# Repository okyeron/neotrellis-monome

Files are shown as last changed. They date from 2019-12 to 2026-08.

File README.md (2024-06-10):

# neotrellis monome compatible grid

## What is it?

Code to use a set of [Adafruit NeoTrellis boards](https://www.adafruit.com/product/3954) as a monome grid clone using an off-the-shelf microcontroller.

Tested mostly using a Teensy 3.2 microcontroller. Teensy 4 should work the same, but it does not have USB pads broken out to use a USB breakout board. 

[There is code](neotrellis_monome_m0) for using an Adafruit SAMD21/51 M0/M4 boards like the Feather and ItsyBitsy, but this will probably require compiling the firmware for your specific board. Compiled firmwares for Feather M4 are in the repo.

Code for [RP2040](neotrellis_monome_rp2040) is also available, but this will probably require compiling the firmware for your specific board.

## compatibility

### Max or other computer-based applications

At the time of writing, this code works as expected with the neotrellis-grid connected to a computer with Max running monome patches.

Some people have reported issues with the neotrellis-grid getting recognized by Windows 10. Windows users are advised to install serialosc 1.4.3 and bonjour print services (v2.0.2?).

### ansible / teletype / trilogy modules

2021 updates to ansible / teletype / trilogy modules now support the neotrellis-grid. It should work without modifications.

### norns /norns shield

As of update version 210607 (June 2021) it should be plug and play. Previous versions are unsupported.

###  Fates

For Fates devices this should be functional by default on the most recent firmwares.

# Build

## BOM:  

8 [Adafruit NeoTrellis driver boards](https://www.adafruit.com/product/3954) [alt [Mouser](https://www.mouser.com/ProductDetail/485-3954) | [Digikey](https://www.digikey.com/products/en?keywords=1528-2712-ND) ]    

8 [Button keypads](http://www.adafruit.com/product/1611) [alt [Mouser](https://www.mouser.com/ProductDetail/485-1611) | [Digikey](https://www.digikey.com/products/en?keywords=1528-1559-ND) ]    

1 [Adafruit micro B USB Breakout](http://www.adafruit.com/product/1833) [alt [Mouser](https://www.mouser.com/ProductDetail/485-1833) | [Digikey](https://www.digikey.com/products/en?keywords=1528-1383-ND) ]    

1 [Teensy 3.2](https://www.pjrc.com/store/teensy32.html) [alt [Adafruit](https://www.adafruit.com/product/2756) ]  

### optional

1 [Adafruit STEMMA/JST-PH 4-pin cable](https://www.adafruit.com/product/3568) - for testing inndividual neotrellis boards before assembly. Cut the cable in half and wire to the appropriate pins on a Teensy or other microcontroller (VIN, GND, SCL, SDA). See the neotrellis boards themselves for the pin-out.

Standard pin headers - 10 1x5 pin headers can be used for joining the neotrellis boards together. [See video](https://www.youtube.com/watch?v=petILmGcNwQ)

Flexible PCB Carrier (Flexi PCB) for mounting the teensy to the neotrellis boards. [Teensy version for sale here](https://www.denki-oto.com/store/p45/Flexible_PCB_Carrier_for_Neotrellis_Grid.html#/)  or [Pico version here](https://www.denki-oto.com/store/p107/Flexible_PCB_Carrier_for_Neotrellis_Grid_and_Pi_Pico.html#/)

Q: Do I need the Flexible PCB Carrier if I have the dink-ii board?
A: No. The dink-ii board replaces the Flexi-PCB.

## before building

* Test each neotrellis board individually using the Adafruit examples in the `File>Examples>Adafruit seesaw Library>Neotrellis` menu. The Basic sketch is good for testing individual boards. The `multitrellis>basic` sketch is good once you have all the boards connected and addresses assigned.

## neotrellis building

* Review the [Adafruit tutorial on the neotrellis](https://learn.adafruit.com/adafruit-neotrellis/arduino-code) boards. 

* [see this video](https://www.youtube.com/watch?v=petILmGcNwQ) for an example of how to join the boards together

## neotrellis address assignment

* [see this graphic](neotrellis_addresses.jpg) for a default layout of addresses and jumper positions for 8 neotrellis boards.

* new default address order in the code for 16x8 layout (__NOTE__ the address are in reverse order in the code - as compared to the graphic above):  
```
  { Adafruit_NeoTrellis(0x32), Adafruit_NeoTrellis(0x30), Adafruit_NeoTrellis(0x2F), Adafruit_NeoTrellis(0x2E)}, // top row
  { Adafruit_NeoTrellis(0x33), Adafruit_NeoTrellis(0x31), Adafruit_NeoTrellis(0x3E), Adafruit_NeoTrellis(0x36) } // bottom row
```

* see this [neotrellis i2c address chart](NeoTrellis_Addresses.txt) if you want to define your own addresses

* Don't worry about the INT pin - it's not used in the grid software.

## firmware flashing - Teensy

### Load pre-compiled firmware w/ TyUploader

Get the firmware "hex" file from directory in this repo (download the entire repo ZIP file - not just individual files).

Get TyTools [from GitHub here](https://github.com/Koromix/tytools/releases). More info here (https://koromix.dev/tytools).

Install TyUploader and open it. Be sure your neotrellis-grid is plugged in. The grid/Teensy should show up in the TyUploader application... or select Teensy or Teensyduino from the pull down menu if needed.

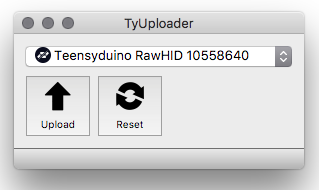
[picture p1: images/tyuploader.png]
tyupdater


Click the Upload button and select the firmware hex file you want to upload. This should upload the firmware and the neotrellis-grid should reboot. That's it.

### If you want to copile the firmware yourself to make changes, etc...

In Arduino/Teensyduino - be sure you have the settings in  `Tools -> USB Type` set to `Serial`

Not critical, but set `Tools -> CPU Speed` to `120 MHz (overclock)`

For reference: [here's a forum post on how to flash Teensy firmware](https://llllllll.co/t/how-to-flash-the-firmware-on-a-teensy-micro-controller/20317)

## other microcontrollers  

See the repo directories for using the Adafruit Neotrellis M4 device (8x4 grid) or SAMD M0/M4 devices (like Adafruit's Feather/ItsyBitsy/QtPy/etc). Precompiled UF2 firmwares are available in those directories for some configurations.

## troubleshooting / testing 

* Triple check your address jumpers - [see this graphic](neotrellis_addresses.jpg) for a default layout of addresses and jumper positions for 8 neotrellis boards.

* Be sure you have the Adafruit Seesaw libraries installed and are up to date (via the Arduino/Teensyduino Library Manager)

* Use the [multitrellis_test](multitrellis_test/multitrellis_test.ino) sketch to test fully assembled grid before flashing neotrellis_monome_teensy.

* Be aware - the multitrellis array will fail to initialize if the addresses are wrong, or the wrong number of boards are attached. If you get no LEDs are just some LEDs - then your addresses are likely the problem.

* There are Teensy specific `i2c_t3` example sketches which can be used to double check your i2c addresses. See `File>Examples>i2c_t3>basic_scanner` in Arduino/Teensyduino for more.

## build help / support / troubleshooting

[see this thread](https://llllllll.co/t/diy-monome-compatible-grid-w-adafruit-neotrellis/28106?u=okyeron) on the lines forum for assistance.

## alternate firmware for color palettes 

https://github.com/oldmanfury/neotrellis-grid-paletted

## testing with serialosc on MacOS

If you already have serialosc installed/running, you may need to unload serialosc to get arduino to properly flash the teensy, then load serialosc to get Max to recognize the grid.  

`launchctl unload /Library/LaunchAgents/org.monome.serialosc.plist`  
`launchctl load /Library/LaunchAgents/org.monome.serialosc.plist`  

Max apps for testing:  
[Monome Home](https://github.com/monome-community/monome-home)  
[test-grid](https://github.com/monome/serialosc.maxpat)  

# Case / Enclosure

[Work in progress](<enclosure/README.md>)

# references

### mext / monome serial protocol

The mext protocol is used for serial communication - same as what is used in most recent monome devices.

### serialosc / libmonome

`serialosc` is required for serial communication with MacOS/Windows computers and OSC devices. Linux may use `serialosc` or `libmonome` depending on the application. `libmonome` is basically driver code which also facillitates monome serial communication.

You can get both `serialosc` and `libmonome` code from [monome github page](https://github.com/monome), and building them is well documented on official linux docs (they work for macOS as well), read part *2 Preparing your system: serialosc* (ignoring the `sudo apt-get` - I was missing `liblo`, but it's available on homebrew): [monome.org/docs/linux/](https://monome.org/docs/linux/).

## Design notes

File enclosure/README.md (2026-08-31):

# neotrellis grid enclosure

This is one example of an enclosure for the neotrellis grid - using a Teensy 3.2 and Adafruit [USB micro breakout](https://www.adafruit.com/product/1833)

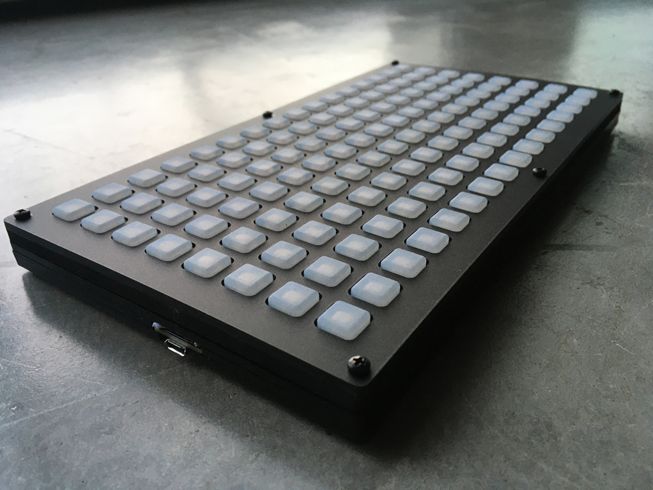
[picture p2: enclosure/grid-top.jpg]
<grid>


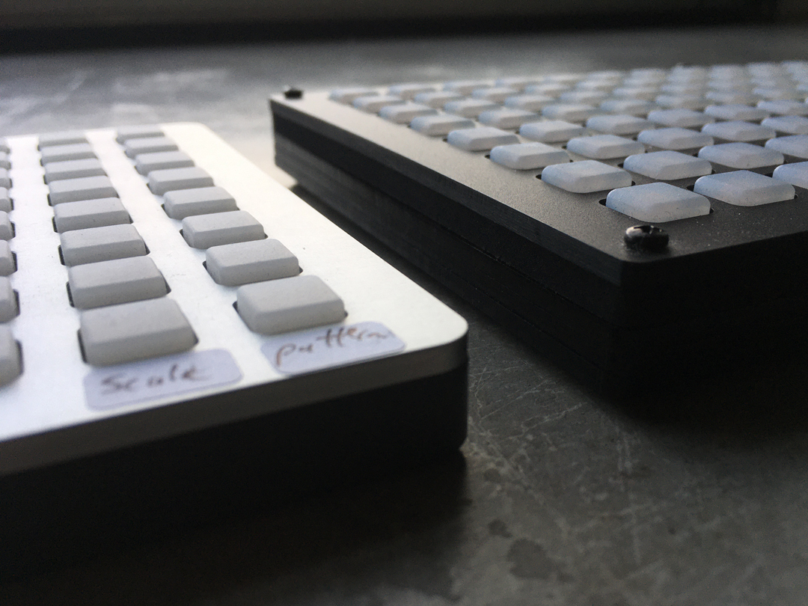
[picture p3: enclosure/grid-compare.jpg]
<grid compare with monome grid>


It's a "stack" of laser cut 3mm acrylic and one layer of 5mm EVA foam. I'm using six 2.5M 11mm standoffs and 2.5M screws to attach everything.  

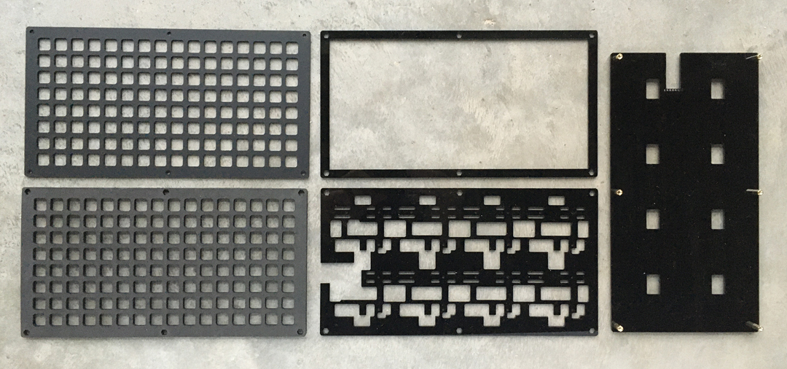
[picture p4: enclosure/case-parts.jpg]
<stack parts>


(this photo is a slightly older layout)

## USB micro breakout

The USB micro breakout is used to breakout 5v power/data from the Teensy and workaround a current limiter on the Teensy 3.2's usb port. This also to provide a cheap and easily replaceable part if the jack gets damaged (Teensy's are a huge pain if the USB jack breaks off).

NOTE - The usb breakout setup here will not work with the Teensy 4. But it appears the Teensy 4 does not have the current limiting issue. However, using a T4 would require a slightly different case design/layout.

# Pins / Soldering / Assembly

## Old way - Free-wiring
Pins used on the Teensy are VIN (5v from USB), GND, D+, D- (SMD pads on the underside), and then SCL (pin 19), SDA (pin 18).  

Put a piece of electrical/kapton tape over the back of the teensy to avoid potential shorts when you stack it up (its a bit of a tight squeeze).  

Just in case - also put a piece of electrical/kapton tape on the neotrellis board under where the teensy sits.  

Putting the Teensy in the case, you want to be sure it's as flat as possible (see pix).

Kinda ugly example of the teensy and usb breakout wiring for this case layout: 

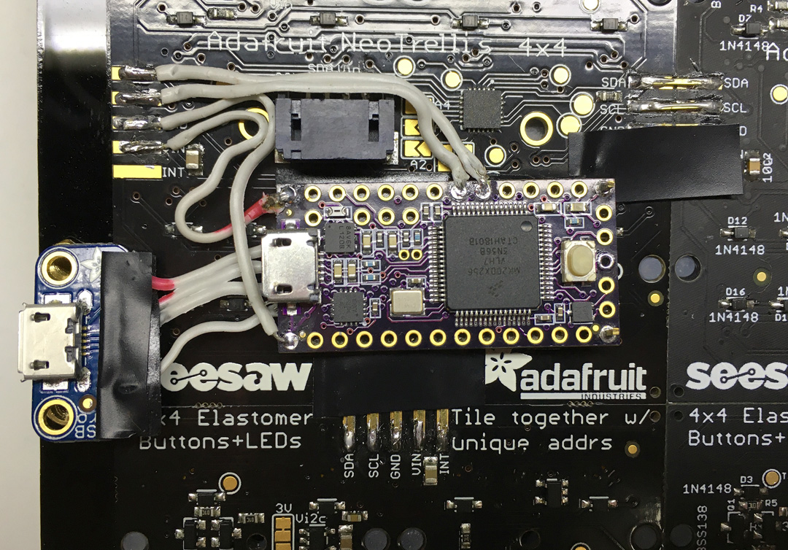
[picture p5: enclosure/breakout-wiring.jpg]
<teensy with usb breakout>


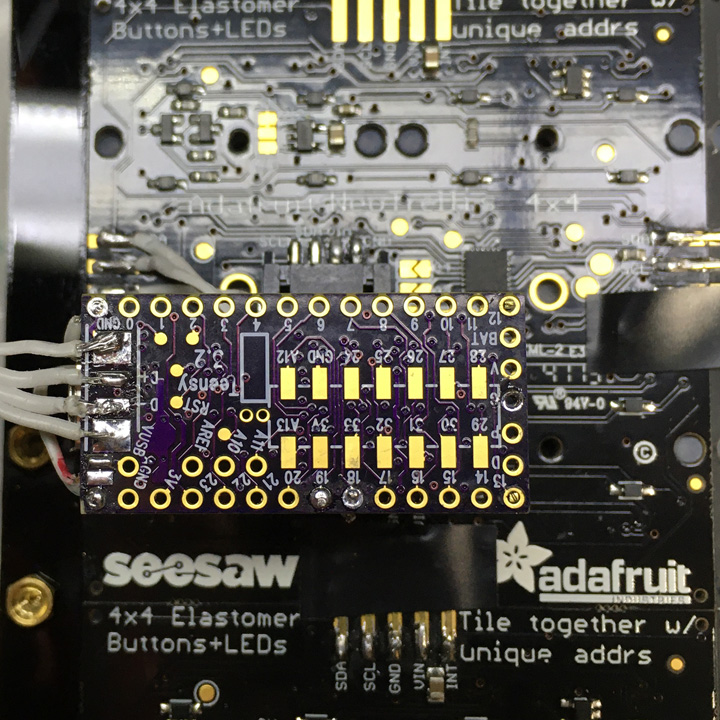
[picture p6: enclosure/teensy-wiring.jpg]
<teensy with usb breakout>


## New way - flexible pcb carrier

As a replacement for the slightly janky free-wiring, I designed a flexible PCB carrier for the Teensy and the USB breakout.

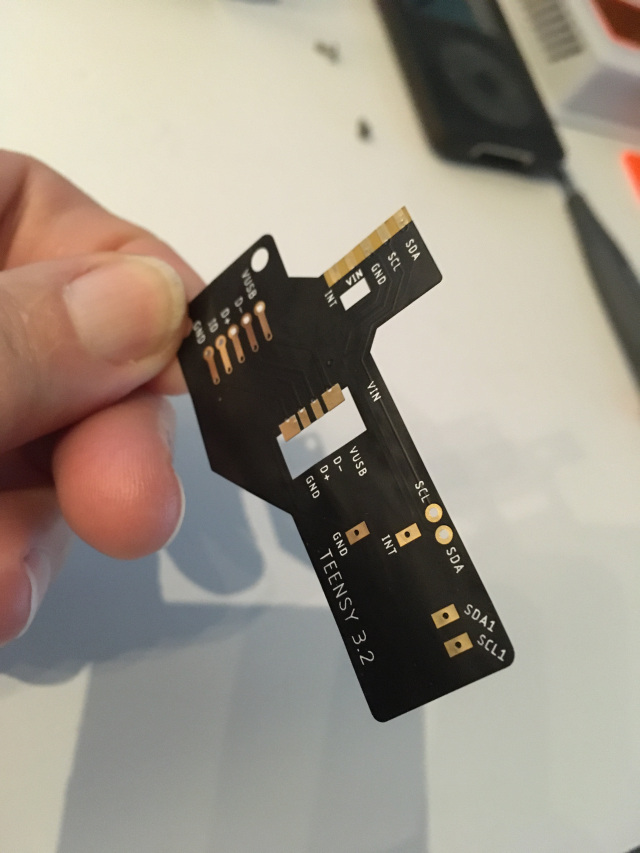
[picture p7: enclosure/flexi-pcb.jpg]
<flexi-pcb>


Unfortunately the flexi-pcb is no longer available.  

## Newest way - use a purpose built controller  

The flex-pcb idea was deprecated as I made the [dink-ii controller](https://denki-oto.com/products/dink-ii-i2c-microcontroller) board which is plug-n-play (no soldering) and less expensive than a combination of other microcontroller + flex-pcb.

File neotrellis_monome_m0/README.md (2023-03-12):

# neotrellis monome compatible grid

Neotrellis Grid Code for Adafruit M0 and M4 controllers.

This code should work with any of the various Adafruit SAMD21/51 M0/M4 controllers such as Feather, ItsyBitsy, etc. 

__NOTE__ - You will need to recompile the code for the specific board you are using. Compiled firmwares such as `neotrellis_m4_8x8_featherM4.UF2` will ONLY work on that specific board type. 

Step 1: Be sure update to the most recent TinyUSB library version. If you're using Arduino, it's best to use Manage Libraries in Arduino to install/update TinyUSB.

Step 2: Be sure you check the board addresses for your build and adjust the code as needed if you do something different than the default described here.

## Adafruit Feather M4 Kit
[Adafruit 8x8 NeoTrellis Feather M4 Kit Pack](https://www.adafruit.com/product/1929)

If you have this (or have built an 8x8 grid with Feather M4) you can use the enclosed compiled firmware [neotrellis_m4_8x8_featherM4.UF2](neotrellis_m4_8x8_featherM4.UF2) assuming your setup uses the following addresses 
```
{ Adafruit_NeoTrellis(0x2E), Adafruit_NeoTrellis(0x30) },
{ Adafruit_NeoTrellis(0x32), Adafruit_NeoTrellis(0x36) }

```

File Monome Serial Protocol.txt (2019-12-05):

## serial protocol

//// input (to serialosc/device)

// sys

/sys/prefix
/sys/port
/sys/host

pattern:	/sys/query
desc:		request device information
serial:		[0x00]

pattern:	/sys/id
desc:		request device ID string
serial:		[0x01]

pattern:	/sys/size
desc:		request grid size
serial:		[0x05]

// led-grid

pattern:	/prefix/led/set x y s
desc:		set led state
args:		x = x value (0-255)
			y = y value (0-255)
			s = on/off (0-1)
serial:		if s = 0, [0x10, x, y]
			if s = 1, [0x11, x, y]

pattern:	/prefix/led/all s
desc:		set all leds
args:		s = on/off (0-1)
serial:		if s = 0, [0x12]
			if s = 1, [0x13]

pattern:	/prefix/led/map x y d[8]
desc:		set 8x8 block of leds, with offset
args:		x = x offset, will be floored to multiple of 8 by firmware
			y = y offset, will be floored to multiple of 8 by firmware
			d[8] = bitwise display data
serial:		[0x14, x, y, d[8]]

pattern:	/prefix/led/row x y d
desc:		set 8x1 block of leds, with offset
args:		x = x offset, will be floored to multiple of 8 by firmware
			y = y offset
			d = bitwise display data
serial:		[0x15, x, y, d]
note:		d can be an array. for each additional element, another serial packet is sent, with x offset incremented by 8.

pattern:	/prefix/led/col x y d
desc:		set 1x8 block of leds, with offset
args:		x = x offset
			y = y offset, will be floored to multiple of 8 by firmware
			d = bitwise display data
serial:		[0x16 x, y, d]
note:		d can be an array. for each additional element, another serial packet is sent, with y offset incremented by 8.

pattern:	/prefix/led/intensity i
desc:		set intensity for entire grid
args:		i = intensity (0-15)
serial:		[0x17, i]

pattern:	/prefix/led/level/set x y i
desc:		set led intensity
args:		x = x value (0-255)
			y = y value (0-255)
			i = intensity (0-255)
serial:		[0x18, x, y, i]

pattern:	/prefix/led/level/all s
desc:		set all leds to level
args:		i = intensity (0-255)
serial:		[0x19, i]

pattern:	/prefix/led/level/map x y d[64]
desc:		set 8x8 block of leds levels, with offset
args:		x = x offset, will be floored to multiple of 8 by firmware
			y = y offset, will be floored to multiple of 8 by firmware
			d[64] = intensities
serial:		[0x1A, x, y, d[64]]

pattern:	/prefix/led/level/row x y d[8]
desc:		set 8x1 block of led levels, with offset
args:		x = x offset, will be floored to multiple of 8 by firmware
			y = y offset
			d[8] = intensities
serial:		[0x1B, x, y, d[8]]
note:		if d[8] has more than 8 elements (multiple of 8) send multiple serial packets with proper offset

pattern:	/prefix/led/level/col x y d[8]
desc:		set 1x8 block of led levels, with offset
args:		x = x offset
			y = y offset, will be floored to multiple of 8 by firmware
			d = bitwise display data
serial:		[0x1C x, y, d[8]]
note:		if d[8] has more than 8 elements (multiple of 8) send multiple serial packets with proper offset

// led-ring

pattern:	/prefix/ring/set n x a
desc:		set led x of ring n to value a
args:		n = ring number
			x = led number
			a = value (0-15)
serial:		[0x90, n, x, a]

pattern:	/prefix/ring/all n a
desc:		set all leds of ring n to a
args:		n = ring number
			a = value
serial:		[0x91, n, a]

pattern:	/prefix/ring/map n d[32]
desc:		set leds of ring n to array d
args:		n = ring number
			d[32] = 64 states, 4 bit values, in 32 consecutive bytes
			d[0] (0:3) value 0
			d[0] (4:7) value 1
			d[1] (0:3) value 2
			....
			d[31] (0:3) value 62
			d[31] (4:7) value 63
serial:		[0x92, n d[32]]

pattern:	/prefix/ring/range n x1 x2 a
desc:		set leds inclusive from x1 and x2 of ring n to a
args:		n = ring number
			x1 = starting position
			x2 = ending position
			a = value
serial:		[0x93, n, x1, x2, a]
note:		set range x1-x2 (inclusive) to a. wrapping supported, ie. set range 60,4 would set values 60,61,62,63,0,1,2,3,4. always positive direction sweep. ie. 4,10 = 4,5,6,7,8,9,10 whereas 10,4 = 10,11,12,13...63,0,1,2,3,4

//// output (from serialosc/device)

// sys

pattern:	/sys/query s n
desc:		device information
serial:		[0x00, s, n]
args:		s = subsection, enumerated as strings [null, "led-grid", "key-grid", "digital-out", "digital-in", "encoder", "analog-in", "analog-out", "tilt", "led-ring"]
			n = number

pattern:	/sys/id s[64]
desc:		device ID string
serial:		[0x01, s[64]]
args:		s = id string, 64 chars

pattern:	/sys/size x y
desc:		grid size
serial:		[0x05, x, y]
args:		x = x size
			y = y size

// key

pattern:	/prefix/key x y s
desc:		key state change
serial:		if s = 0 [0x00, x, y] key up
			if s = 1 [0x01, x, y] key down
args:		x = x position
			y = y position

// encoder

pattern:	/prefix/enc/delta n d
desc:		encoder position change
serial:		[0x50, n, d]
args:		n = encoder number
			d = delta (signed char)

pattern:	/prefix/enc/key n d
desc:		encoder position change
serial:		if d = 0 [0x51 n] key up
			if d = 1 [0x52 n] key down
args:		n = encoder number

monome protocol
---------------

- extended to support variety of control, room for extensibility
- to be implemented on mk, new editions, arc, arc-variants (axis?)
- take advantage of i2c device chain system
- remove dependence on device usb serial number, replace with query system

notes
-----

new serial prefix: tty.usbserial-m0000000

mk set-number of grids, firmware versions for each size 1/2/4

should grid offsets live inside the grid subsystem?
	applies to both led-grid and key-grid.
	should each have it's own?

"all" vs "clear"

legacy bridge
	ie /press => /key
	ie /clear => /led/all 0

structure
---------

first byte of packet is identifier in the form:

[(a << 4) + b]

a = section (ie. system, key-grid, digital, encoder, led grid, tilt)
b = command (ie. query, enable, led, key, frame)

organized by section:

---------------------------------------------------------------------
0 system
---------------------------------------------------------------------

note: most of these messages are not accessible via OSC
	intended for device configuration

to device:
----------

OSC:
/sys/query
	mapped to 0x00
/sys/id
	mapped to 0x01
/sys/size
	mapped to 0x05

0x00 system / query
bytes: 1
structure: [0x00]
description: request device information
action: response, 0x00 (see below)
OSC: /sys/query

0x01 system / query ID
bytes: 1
structure: [0x01]
description: request device ID (text string, trailing space needs to be stripped)
action: response, 0x01 (see below)

0x02 system / write ID
bytes: 33
structure: [0x02, d0..31]
description: write ID (text string)
response: confirms written id, 0x01

0x03 system / request grid offsets
bytes: 1
structure: [0x03]
description: request grid offsets. device will respond for each connected grid.
action: response, 0x02

0x04 system / set grid offset
bytes: 4
structure: [0x04, n, x, y]
n = grid number
x = x offset (floored to multiple of 8 by firmware)
y = y offset (floored to multiple of 8 by firmware)
description: set grid offset to (x, y)

0x05 system / request grid size
bytes: 1
structure: [0x05]
description: request grid size. device will respond with x,y
action: response, 0x03

0x06 system / set grid size
bytes: 3
structure: [0x06, x, y]
x = x size
y = y size
description: set grid size to (x, y)

0x07 system / get ADDR (scan)
bytes: 1
structure: [0x07]
description: request list of connected components (i2c ADDRs)

0x08 system / set ADDR
bytes: 3
structure: [0x08, a, b]
a = ADDR to set
b = new ADDR value
description: set ADDR. writes internal eeprom. probably should reset afterwards?

0x0F system / query firmware version
bytes: 1
structure: [0x0F]
description: request firmware version

from device:
------------

OSC:
/sys/query
	mapped to 0x00
/sys/id
	mapped to 0x01
/sys/size
	mapped to 0x03

0x00 system / query response
bytes: 3
structure: [0x00, a, b]
a = section (grids, encs)
	1-15 (0 is system)
b = number (how many connected)
	0-255
description: response to request for component availability. multiple responses will be sent, one for each section. for example, if two grids are connected and 8 encoders, the response would be [0,1,2] [0,2,8]
OSC: /sys/query a b
	where a is a text translation, b is number available. a = [null, "led-grid", "key-grid", "digital-out", etc]

0x01 system / ID
bytes: 33
structure: [0x01, d0..31]
description: respond with ID (text string)

0x02 system / report grid offset
bytes: 4
structure: [0x02, n, x, y]
n = grid number
x = x offset
y = y offset
description: response to query, grid offset (x, y)

0x03 system / report grid size
bytes: 3
structure: [0x03, x, y]
x = x
y = y
description: response to query, grid size (x, y)

0x04 system / report ADDR
bytes: 3
structure: [0x0F, a, b]
a = ADDR
description: found device at ADDR, type b

0x0F system / report firmware version
bytes: 9
structure: [0x0F, v[8]]
v = version, 8 character string
description: firmware version

---------------------------------------------------------------------
1 led-grid
---------------------------------------------------------------------

to device:
----------

OSC:
/led/set x y [0/1]
	mapped to 0x10 and 0x11
/led/all [0/1]
	mapped to 0x12 and 0x13
/led/map x y d[8]
	mapped to 0x14
/led/row x y d
	mapped to 0x15
/led/col x y d
	mapped to 0x16
/led/intensity x
	mapped to 0x17

0x10 led-grid / led off
bytes: 3
structure: [0x10, x, y]
description: turn off led at (x,y)

0x11 led-grid / led on
bytes: 3
structure: [0x11, x, y]
description: turn on led at (x,y)

0x12 led-grid / all off
bytes: 1
structure: [0x12]
description: all leds off

0x13 led-grid / all on
bytes: 1
structure: [0x13]
description: all leds on

0x14 led-grid / map (frame)
bytes: 11
structure: [0x14, x, y, d0..7]
x = x offset (floored to multiple of 8 by firmware)
y = y offset (floored to multiple of 8 by firmware)
d = led states, 8x8 block (64 bits, 8 bytes)
	sequential bytes represent rows (series of x values)
description: write 8x8 block of led data

0x15 led-grid / row
bytes: 4
structure: [0x15, x, y, d]
x = x offset (floored to multiple of 8 by firmware)
y = y value
d = led states, 8 bits
	bitwise
description: write row of 8 bits at y, offset by x

0x16 led-grid / col
bytes: 4
structure: [0x15, x, y, d]
x = x value
y = y offset (floored to multiple of 8 by firmware)
d = led states, 8 bits
	bitwise
description: write row of 8 bits at x, offset by y

0x17 led-grid / intensity
bytes: 2
structure: [0x18, a]
a = intensity
	0-255 (scaled inside firmware)
description: change overall led intensity

0x18 led-grid / set led intensity
bytes: 4
structure: [0x18, x, y, i]
i = intensity
	0-255 (scaled inside firmware)
description: set led (x,y) to intensity i

0x19 led-grid / set all leds to specified intensity
bytes: 2
structure: [0x19, i]
i = intensity
	0-255 (scaled inside firmware)
description: set all leds to intensity i

0x1A led-grid / map intensity
bytes: 67
structure: [0x14, x, y, d0..63]
x = x offset (floored to multiple of 8 by firmware)
y = y offset (floored to multiple of 8 by firmware)
d = led intensities, 8bit each
description: write 8x8 block of led intensity data

0x1B led-grid / row intensity
bytes: 11
structure: [0x15, x, y, d0..8]
x = x offset (floored to multiple of 8 by firmware)
y = y value
d = led intensities, 8 bytes
description: set led intensities at row y, offset by x

0x1C led-grid / col intensity
bytes: 11
structure: [0x15, x, y, d0..8]
x = x value
y = y offset (floored to multiple of 8 by firmware)
d = led intensities, 8 bytes
description: set led intensities at col x, offset by y

from device:
------------

---------------------------------------------------------------------
2 key-grid
---------------------------------------------------------------------

to device:
----------

from device:
------------

OSC:
/key x y [0/1]
	mapped to 0x20 and 0x21

0x20 key-grid / key up
bytes: 3
structure: [0x20, x, y]
description: key up at (x,y)

0x21 key-grid / key down
bytes: 3
structure: [0x21, x, y]
description: key down at (x,y)

---------------------------------------------------------------------
3 digital-out
---------------------------------------------------------------------

to device:
----------

OSC:
/digital/out/set x [0/1]
	mapped to 0x30 and 0x31
/digital/out/clear [0/1]
	mapped to 0x32 and 0x33
/digital/out/block offset d
	mapped to 0x34
/digital/out/map d[32]
	mapped to 0x35

0x30 d-out / set off
bytes: 2
structure: [0x30, x]
description: turn off digital out at (x)

0x31 d-out / set on
bytes: 2
structure: [0x31, x]
description: turn on digital out at (x)

0x32 d-out / set all off
bytes: 1
structure: [0x32]
description: turn off all digital outs

0x33 d-out / set all on
bytes: 1
structure: [0x33]
description: turn on all digital outs

0x34 d-out / set block
bytes: 3
structure: [0x34, a, b]
a = block offset (floored to multiple of 8 by firmware)
b = digital states, bitwise
	8 bits
description: set block of 8 bits, offset by multiple of 8

0x35 d-out / set all
bytes: 33
structure: [0x35, d0..31]
d = digital states, bitwise
	255 bits (32 bytes)
description: set all digital states

from device:
------------

---------------------------------------------------------------------
4 digital-line-in
---------------------------------------------------------------------

to device:
----------

from device:
------------

OSC:
/digital/in n [0/1]
	mapped to 0x40 and 0x41

0x40 d-line-in / change to low
bytes: 2
structure: [0x40, x]
description: switch change low at (x)

0x41 d-line-in / change to high
bytes: 3
structure: [0x41, x]
description: switch change high at (x,y)

---------------------------------------------------------------------
5 encoder
---------------------------------------------------------------------

to device:
----------

from device:
------------

OSC:
/enc/delta n d
	mapped to 0x50
/enc/key n [0/1]
	mapped to 0x51 and 0x52

0x50 enc / delta
bytes: 3
structure: [0x50, n, d]
n = encoder number
	0-255
d = delta
	(-128)-127 (two's comp 8 bit)
description: encoder position change

0x51 enc / switch up
bytes: 2
structure: [0x51, n]
n = encoder number
	0-255
description: encoder switch up

0x52 enc / switch down
bytes: 2
structure: [0x52, n]
n = encoder number
	0-255
description: encoder switch down

---------------------------------------------------------------------
6 analog in
---------------------------------------------------------------------

to device:
----------

OSC:
/analog/input/active
	mapped to 0x60
/analog/input/set n [0/1]
	mapped to 0x61 and 0x62

0x60 analog / state request
bytes: 2
structure: [0x80]
description: request active states. device will reply with list.

0x61 analog / set state on
bytes: 2
structure: [0x61, n]
n = number
	0-255
description: enable individual analog input.

0x62 analog / set state off
bytes: 2
structure: [0x62, n]
n = number
	0-255
description: disable individual analog input.

from device:
------------

OSC:
/analog/input/active d[32]
	mapped to 0x60
/analog/input n x
	mapped to 0x61

0x60 analog / active response
bytes: 33
structure: [0x01, d0..31]
d = states (32 bytes)
	bitwise for total of 255 bits
description: report which individual inputs are active

0x61 analog in
bytes: 4
structure: [0x61, n, dh, dl]
n = number
	0-255
(dh << 8) + dl = value (16 bit)
	data high, data low
description: analog input

---------------------------------------------------------------------
7 analog out
---------------------------------------------------------------------

to device:
----------

OSC:
/analog/out n x
	mapped to 0x70

0x70 analog out
bytes 4
structure: [0x70, n, dh, dl]
n = number
	0-255
(dh << 8) + dl = value (16 bit)
	data high, data low
description: analog output

from device:
------------

---------------------------------------------------------------------
8 tilt
---------------------------------------------------------------------

to device:
----------

OSC:
/tilt/active
	mapped to 0x80
/tilt/set n [0/1]
	mapped to 0x81 and 0x82

0x80 tilt / state request
bytes: 2
structure: [0x80]
description: request active states. device will reply with list.

0x81 tilt / set state on
bytes: 2
structure: [0x81, n]
n = number
	0-7
description: enable individual tilt sensor.

0x82 tilt / set state off
bytes: 2
structure: [0x82, n]
n = number
	0-7
description: disable individual tilt sensor.

from device:
------------

OSC:
/tilt/active d
	mapped to 0x80
/tilt n x y z
	mapped to 0x81

0x80 tilt / active response
bytes: 9
structure: [0x01, d]
d = state (8 bits)
	up to 8 tilt sensors
description: report which tilt sensors are active

0x81 tilt
bytes 8
structure: [0x80, n, xh, xl, yh, yl, zh, zl]
n = sensor number (support for multiple accelerometers)
description: 16-bit tilt input for x, y, z axis

---------------------------------------------------------------------
9 variable 64led ring
---------------------------------------------------------------------

to device:
----------

OSC:
/ring/all n a
	mapped to 0x90
/ring/set n x a
	mapped to 0x91
/ring/map n d[64]
	mapped to 0x92
/ring/line n x1 x2 a
	mapped to 0x93

0x90 set single led
bytes: 4
structure: [0x90, n, x, a]
n = group number
x = led number
a = value
description: set led x of group n to value a

0x91 set all to a
bytes: 3
structure: [0x91, n, a]
n = group number (led ring number)
a = value
description: set entire group to value a

0x92 set all values to d (64)
bytes: 66
structure: [0x92, n, d0..63]
n = group number
d = array of 64 values
description: set all values of group to d (array)

0x93 set range of elements to a
bytes: 5
structure: [0x93, n, x1, x2, a]
n = group number
x1 = start position
x2 = end position
a = value
description: set range x1-x2 (inclusive) to a. wrapping supported, ie. set range 60,4 would set values 60,61,62,63,0,1,2,3,4. always positive direction sweep. ie. 4,10 = 4,5,6,7,8,9,10 whereas 10,4 = 10,11,12,13...63,0,1,2,3,4

from device:
------------

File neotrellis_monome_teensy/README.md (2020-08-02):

# neotrellis monome grid with teensy 3.2

## hex files

The hex files here are setup with the following addresses:

```
// 16x8 
Adafruit_NeoTrellis trellis_array[NUM_ROWS / 4][NUM_COLS / 4] = {
  { Adafruit_NeoTrellis(0x32), Adafruit_NeoTrellis(0x30), Adafruit_NeoTrellis(0x2F), Adafruit_NeoTrellis(0x2E)}, // top row
  { Adafruit_NeoTrellis(0x33), Adafruit_NeoTrellis(0x31), Adafruit_NeoTrellis(0x3E), Adafruit_NeoTrellis(0x36) } // bottom row
};
```

```
// 8x8 setup
Adafruit_NeoTrellis trellis_array[NUM_ROWS / 4][NUM_COLS / 4] = {
	{ Adafruit_NeoTrellis(0x2F), Adafruit_NeoTrellis(0x2E) },
	{ Adafruit_NeoTrellis(0x3E), Adafruit_NeoTrellis(0x36) }
};
```

These are in order right to left as you look at the BACK of the grid. So from the front/grid side, these will be flipped.

* see this graphic for a default layout of addresses and jumper positions for 8 neotrellis boards (16x8 layout). For an 8x8 just use the left half.  

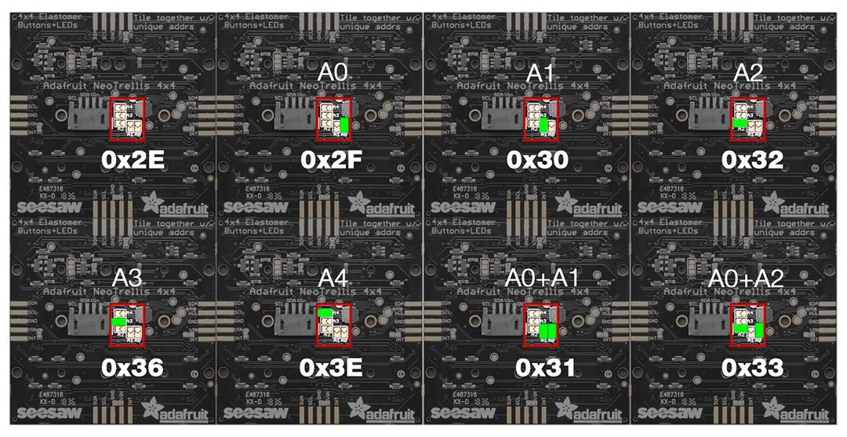
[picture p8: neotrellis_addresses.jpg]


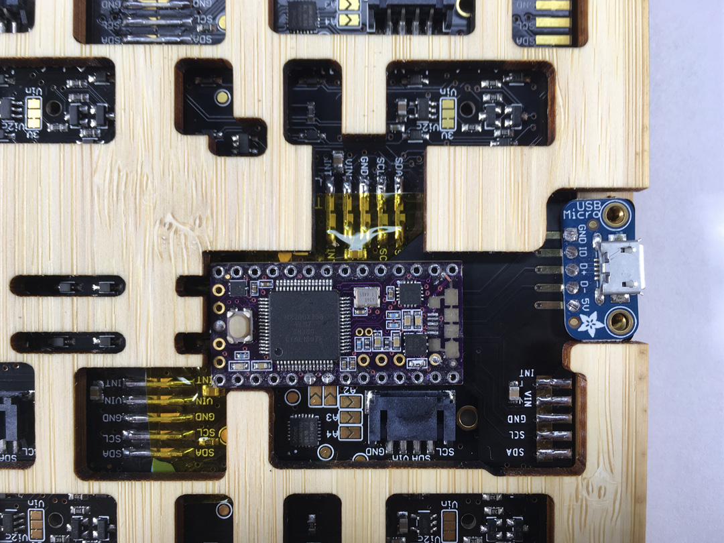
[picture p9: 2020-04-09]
enclosure/flexi-pcb2-1080.jpg

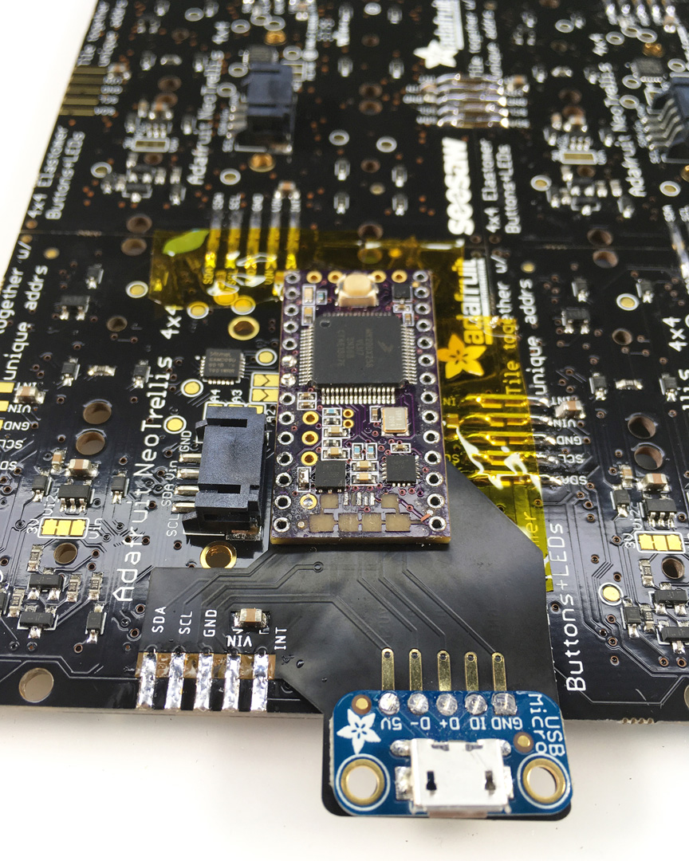
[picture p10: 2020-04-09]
enclosure/flexi-pcb-1080.jpg

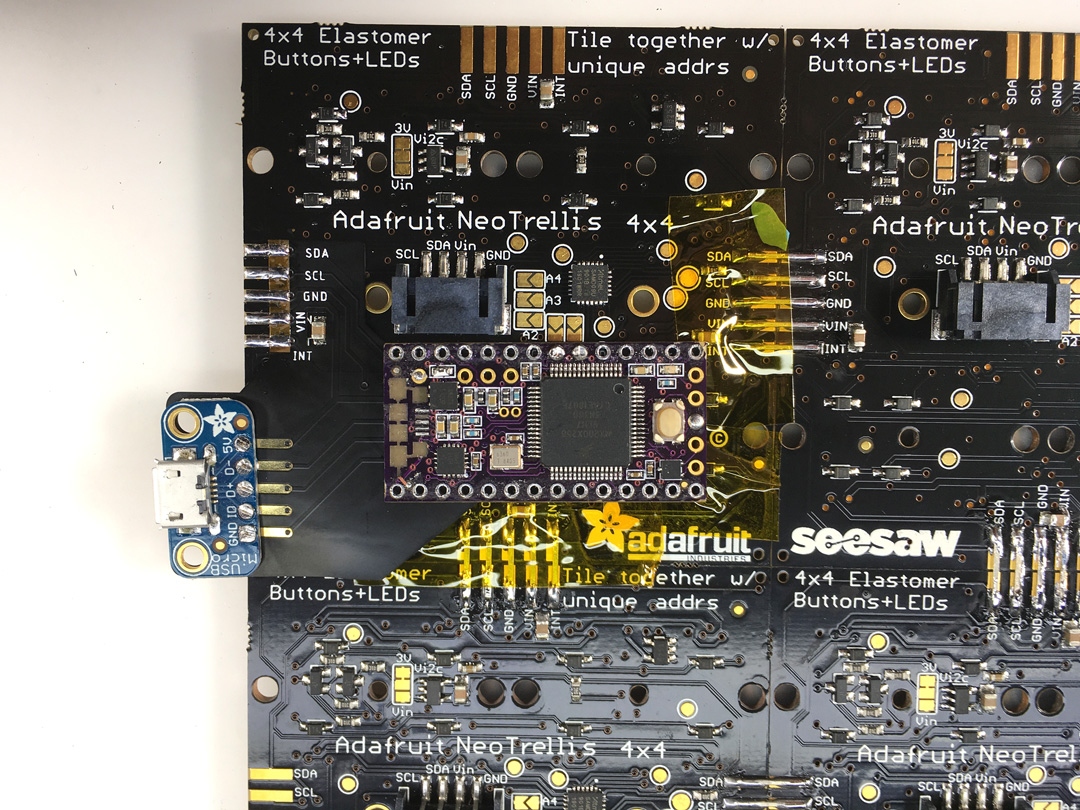
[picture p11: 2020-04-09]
enclosure/flexi-pcb4-1080.jpg

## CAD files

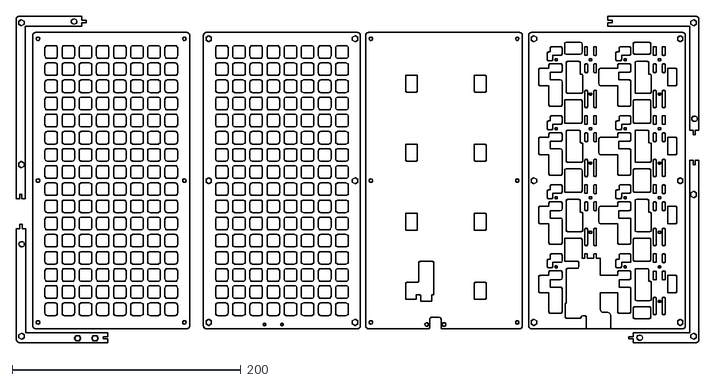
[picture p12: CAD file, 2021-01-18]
enclosure/neotrellis-128-12-cut.dxf
597.1 x 285.2

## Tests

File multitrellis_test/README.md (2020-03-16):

# neotrellis multi-trellis test script

Using default layout for 16x8 grid, this will light up each button with rainbow colors on startup and then you can press each button to check functionality.

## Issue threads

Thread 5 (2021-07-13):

DEV_TYPE_COUNT_PHYSICAL has been removed upstream

mgdde, 2021-07-13:
The line
#define DEV_TYPE_COUNT_PHYSICAL 4
has been removed from norns/matron/src/device/device_common.h and that breaks compilation. As a quick fix I added the above line to device_monitor.c locally and the build worked.

okyeron, 2021-09-23:
Apologies for not checking in here much.

Which compilation does/did that break? Is this still an issue with the latest norns updates?

Closed 2023-12-06.

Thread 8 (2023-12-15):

AI files don't work out of the box with Ponoko uploader

Scott-at-Ponoko, 2023-12-15:
Hi there,

Scott here, one of the fine folk on the Ponoko customer team 😄 We're a laser cutting service in California.

We had a customer recently attempt to use your AI files to have the enclosure parts for this project manufactured with us. I downloaded the raw AI files from here:

https://github.com/okyeron/neotrellis-monome/tree/main/enclosure/individual-layers

This resulted in files that opened OK in Illustrator, but they did not upload successfully to our site. Something about the formatting or contents was preventing our AI parser from reading them in correctly.

I was able to remedy this by resaving them all as SVG v1.1 from Illustrator. Not sure exactly what the issue was with the originals, though; I didn't see any red flags in the layer structure 🤔 Also, resaving them as AI files (Illustrator 2020 format version) notably did *not* result in files that would successfully upload to our site. When resaving as SVG, though, I did get a "transforms are expanded" warning. Weird!

Anyhow, I thought I'd bring this up as it's possible more folks might try to use your files to put one of these together. Much better if the files are usable out of the gate via as many laser cutting services as possible, I reckon! I'm unable to attach the resaved SVG files I generated, but I'm happy to make them available to you for your convenience. Let me know if there's anything else I can do to help!

Scott-at-Ponoko, 2023-12-27:
OK, on second pass, downloading files individually from t eh repo seems to result in AI files that open in Illustrator, but do not upload correctly to Ponoko.

*But*, downloading a zip of the whole shebang "neotrellis-monome-main", and then extracting the AI files from there, *does* result in files that upload OK to Ponoko. I guess something about the original download process I used fouled the .AI formatting just enough that the Ponoko uploader thought they were sus. Problem solved!

Gonna leave this up here, just in case anyone else using your files has similar issues. Whew! :-)

Closed 2023-12-27.

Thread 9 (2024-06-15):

Flexible PCB design files missing

cdd3, 2024-06-15:
It would be really great if you could post the design files for the flexible PCB carriers for the Teensy & RP2040 since they're sold out.

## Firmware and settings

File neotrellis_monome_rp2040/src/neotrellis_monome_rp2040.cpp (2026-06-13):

/***********************************************************
 *  DIY monome compatible grid w/ Adafruit NeoTrellis
 *  for RP2040 Pi Pico
 *  
 *  This code makes the Adafruit Neotrellis boards into a Monome compatible grid via monome's mext protocol
 *  ----> https://www.adafruit.com/product/3954
 *  
 *  Code here is for a 16x8 grid, but can be modified for 4x8, 8x8, or 16x16 (untested on larger grid arrays)
 *  
 *  Many thanks to: 
 *  scanner_darkly <https://github.com/scanner-darkly>, 
 *  TheKitty <https://github.com/TheKitty>, 
 *  Szymon Kaliski <https://github.com/szymonkaliski>, 
 *  John Park, Todbot, Juanma, Gerald Stevens, and others
 *
*/

// SET TOOLS USB STACK TO TinyUSB

// RP2040 BOARDS REQUIRE Earle Philhower's Arduino core for RP2040 devices, arduino-pico
// See https://learn.adafruit.com/rp2040-arduino-with-the-earlephilhower-core/overview

// Be sure you have these libraries installed
//    Adafruit seesaw library 
//    elapsedMillis
//    Adafruit TinyUSB Library
//    Adafruit NeoPixel

#include "MonomeSerialDevice.h"
#include <Adafruit_NeoTrellis.h>

#include <Arduino.h>
#include <Adafruit_TinyUSB.h>
#include <elapsedMillis.h>

#include "i2c_config.h" // look here to change settings for different boards

#define NUM_ROWS 8 // DIM_Y number of rows of keys down
#define NUM_COLS 16 // DIM_X number of columns of keys across
#define NUM_LEDS NUM_ROWS*NUM_COLS

#define INT_PIN 9
#define LED_PIN 13 // teensy LED used to show boot info

// This assumes you are using a USB breakout board to route power to the board 
// If you are plugging directly into the controller, you will need to adjust this brightness to a much lower value
#define BRIGHTNESS 255 // overall grid brightness - use gamma table below to adjust levels

#define R 255
#define G 255
#define B 255

// gamma table for 16 levels of brightness
const uint8_t gammaTable[16] = { 0,  2,  3,  6,  11, 18, 25, 32, 41, 59, 70, 80, 92, 103, 115, 128}; 


bool isInited = false;
elapsedMillis monomeRefresh;

// set your monome device name here
String deviceID = "neo-monome";
String serialNum = "m4216126";

// DEVICE INFO FOR TinyUSB
char mfgstr[7] = "monome";
char prodstr[5] = "grid";
char serialstr[9] = "m4216126";

// Monome class setup
MonomeSerialDevice mdp;

int prevLedBuffer[mdp.MAXLEDCOUNT]; 


// NeoTrellis setup
/*
// 8x8 setup RP2040
Adafruit_NeoTrellis trellis_array[NUM_ROWS / 4][NUM_COLS / 4] = {
  { Adafruit_NeoTrellis(addrRowOne[0], &MYWIRE), Adafruit_NeoTrellis(addrRowOne[1], &MYWIRE) },
  { Adafruit_NeoTrellis(addrRowTwo[0], &MYWIRE), Adafruit_NeoTrellis(addrRowTwo[1], &MYWIRE) }
};
*/
// 16x8 RP2040
Adafruit_NeoTrellis trellis_array[NUM_ROWS / 4][NUM_COLS / 4] = {
  { Adafruit_NeoTrellis(addrRowOne[0], &MYWIRE), Adafruit_NeoTrellis(addrRowOne[1], &MYWIRE), Adafruit_NeoTrellis(addrRowOne[2], &MYWIRE), Adafruit_NeoTrellis(addrRowOne[3], &MYWIRE)}, // top row
  { Adafruit_NeoTrellis(addrRowTwo[0], &MYWIRE), Adafruit_NeoTrellis(addrRowTwo[1], &MYWIRE), Adafruit_NeoTrellis(addrRowTwo[2], &MYWIRE), Adafruit_NeoTrellis(addrRowTwo[3], &MYWIRE) } // bottom row
};

Adafruit_MultiTrellis trellis((Adafruit_NeoTrellis *)trellis_array, NUM_ROWS / 4, NUM_COLS / 4);


// ***************************************************************************
// **                                HELPERS                                **
// ***************************************************************************

// Pad a string of length 'len' with nulls
void pad_with_nulls(char* s, int len) {
  int l = strlen(s);
  for( int i=l;i<len; i++) {
    s[i] = '\0';
  }
}

// Input a value 0 to 255 to get a color value.
// The colors are a transition r - g - b - back to r.
uint32_t Wheel(byte WheelPos) {
  if(WheelPos < 85) {
   return seesaw_NeoPixel::Color(WheelPos * 3, 255 - WheelPos * 3, 0);
  } else if(WheelPos < 170) {
   WheelPos -= 85;
   return seesaw_NeoPixel::Color(255 - WheelPos * 3, 0, WheelPos * 3);
  } else {
   WheelPos -= 170;
   return seesaw_NeoPixel::Color(0, WheelPos * 3, 255 - WheelPos * 3);
  }
  return 0;
}

// ***************************************************************************
// **                          FUNCTIONS FOR TRELLIS                        **   
// ***************************************************************************


//define a callback for key presses
TrellisCallback keyCallback(keyEvent evt){
  uint8_t x  = evt.bit.NUM % NUM_COLS;
  uint8_t y = evt.bit.NUM / NUM_COLS; 

  if(evt.bit.EDGE == SEESAW_KEYPAD_EDGE_RISING){
//     Serial.println(" pressed ");
    mdp.sendGridKey(x, y, 1);
  }else if(evt.bit.EDGE == SEESAW_KEYPAD_EDGE_FALLING){
//     Serial.println(" released ");
    mdp.sendGridKey(x, y, 0);
  }
  //sendLeds();
  //trellis.show();
  return 0;
}


// ***************************************************************************
// **                                SEND LEDS                              **
// ***************************************************************************

void sendLeds(){
  uint8_t value, prevValue = 0;
  uint32_t hexColor;
  bool isDirty = false;
  
  for(int i=0; i< NUM_ROWS * NUM_COLS; i++){
    value = mdp.leds[i];
    prevValue = prevLedBuffer[i];
    uint8_t gvalue = gammaTable[value];
    
    if (value != prevValue) {
      //hexColor = (((R * value) >> 4) << 16) + (((G * value) >> 4) << 8) + ((B * value) >> 4); 
      hexColor =  (((gvalue*R)/256) << 16) + (((gvalue*G)/256) << 8) + (((gvalue*B)/256) << 0);
      trellis.setPixelColor(i, hexColor);

      prevLedBuffer[i] = value;
      isDirty = true;
    }
  }
  if (isDirty) {
    trellis.show();
  }

}

// ***************************************************************************
// **                                 SETUP                                 **
// ***************************************************************************

void setup(){
	uint8_t x, y;

	TinyUSBDevice.setManufacturerDescriptor(mfgstr);
	TinyUSBDevice.setProductDescriptor(prodstr);
	TinyUSBDevice.setSerialDescriptor(serialstr);
  
	Serial.begin(115200);
  
  // while( !TinyUSBDevice.mounted() ) delay(1);

	MYWIRE.setSDA(I2C_SDA);
	MYWIRE.setSCL(I2C_SCL);

Serial.println(I2C_SDA);
Serial.println(I2C_SCL);

	mdp.isMonome = true;
	mdp.deviceID = deviceID;
	mdp.setupAsGrid(NUM_ROWS, NUM_COLS);
  	monomeRefresh = 0;
  	isInited = true;

	int var = 0;
	while (var < 8) {
		mdp.poll();
		var++;
		delay(100);
	}

	if (!trellis.begin()) {
		Serial.println("trellis.begin() failed!");
		Serial.println("check your addresses.");
		Serial.println("reset to try again.");
		while(1);  // loop forever
	}

	// key callback
	for (x = 0; x < NUM_COLS; x++) {
		for (y = 0; y < NUM_ROWS; y++) {
			trellis.activateKey(x, y, SEESAW_KEYPAD_EDGE_RISING, true);
			trellis.activateKey(x, y, SEESAW_KEYPAD_EDGE_FALLING, true);
			trellis.registerCallback(x, y, keyCallback);
		}
	}

	// set overall brightness for all pixels
	for (x = 0; x < NUM_COLS / 4; x++) {
		for (y = 0; y < NUM_ROWS / 4; y++) {
		  trellis_array[y][x].pixels.setBrightness(BRIGHTNESS);
		}
	}

	// clear grid leds
	mdp.setAllLEDs(0);
	sendLeds();
	
    // blink one led to show it's started up
    trellis.setPixelColor(0, 0xFFFFFF);
    trellis.show();
    delay(100);
    trellis.setPixelColor(0, 0x000000);
    trellis.show();
}



// ***************************************************************************
// **                                 LOOP                                  **
// ***************************************************************************

void loop() {

    mdp.poll(); // process incoming serial from Monomes
 
    // refresh every 16ms or so
    if (isInited && monomeRefresh > 16) {
        trellis.read();
        sendLeds();
        monomeRefresh = 0;
    }

}

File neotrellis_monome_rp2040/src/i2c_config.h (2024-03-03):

#include <stdint.h> 

// I2C CONFIG 

#undef I2C_SDA
#undef I2C_SCL

#define PICO 1
#define KB2040QT 2
#define FEATHER2040QT 3

// DEFINE WHAT BOARD YOU ARE USING
// PICO OR KB2040QT or FEATHER2040QT
// change platformio.ini board to use `adafruit_feather`
#ifndef BOARDTYPE
#define BOARDTYPE PICO
#endif

// SET YOUR ADDRESSES 
// 16x8
const uint8_t addrRowOne[4] = {0x32,0x30,0x2F,0x2E}; 
const uint8_t addrRowTwo[4] = {0x33,0x31,0x3E,0x36}; 

// 8x8
// const byte addrRowOne[4] = {0x2F,0x2E}; 
// const byte addrRowTwo[4] = {0x32,0x30}; 

 
// KeeBoar KB2040 - STEMMA-QT uses 12/13 and Wire
#if BOARDTYPE == KB2040QT
  #define MYWIRE Wire
  #define I2C_SDA 12
  #define I2C_SCL 13
#endif

// Feather RP2040 - STEMMA-QT uses 2/3 and Wire
#if BOARDTYPE == FEATHER2040QT
  #define MYWIRE Wire
  #define I2C_SDA 2
  #define I2C_SCL 3
#endif

// DEFAULT FOR PICO
#ifndef I2C_SDA
#define I2C_SDA 26
#endif
#ifndef I2C_SCL
#define I2C_SCL 27
#endif
#ifndef MYWIRE
#define MYWIRE Wire1
#endif

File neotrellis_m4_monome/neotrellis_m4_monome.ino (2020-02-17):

// SET TOOLS USB STACK TO TinyUSB

#include "NeoTrellisM4.h"
#include "MonomeSerialDevice.h"
#include <Adafruit_TinyUSB.h>
#include <elapsedMillis.h>

#define NUM_ROWS 4 // DIM_Y number of rows of keys down
#define NUM_COLS 8 // DIM_X number of columns of keys across
#define NUM_LEDS NUM_ROWS*NUM_COLS

#define BRIGHTNESS 255 // overall grid brightness - use gamma table below to adjust levels

#define R 255
#define G 255
#define B 255

// DEVICE INFO FOR ADAFRUIT M0 or M4 
char mfgstr[32] = "monome";
char prodstr[32] = "monome";
char serialstr[32] = "m4676123";

// set your monome device name here
String deviceID = "neo-monome";
String serialNum = "m4676123";

elapsedMillis monomeRefresh;
bool isInited = false;

int prevLedBuffer[32]; 

// Monome class setup
MonomeSerialDevice mdp;


// The NeoTrellisM4 object is a keypad and neopixel strip subclass
// that does things like auto-update the NeoPixels and stuff!
NeoTrellisM4 trellis = NeoTrellisM4();

// gamma table for 16 levels of brightness
const uint8_t gammaTable[16] = { 0,  2,  3,  6,  11, 18, 25, 32, 41, 59, 70, 80, 92, 103, 115, 128}; 


// ***************************************************************************
// **                                HELPERS                                **
// ***************************************************************************

// Pad a string of length 'len' with nulls
void pad_with_nulls(char* s, int len) {
  int l = strlen(s);
  for( int i=l;i<len; i++) {
    s[i] = '\0';
  }
}


// ***************************************************************************
// **                          FUNCTIONS FOR TRELLIS                        **   
// ***************************************************************************


// ***************************************************************************
// **                                 SETUP                                 **
// ***************************************************************************


void setup() {
  // for Adafruit M0 or M4
  pad_with_nulls(mfgstr, 32);
  pad_with_nulls(prodstr, 32);
  pad_with_nulls(serialstr, 32);
  USBDevice.setManufacturerDescriptor(mfgstr);
  USBDevice.setProductDescriptor(prodstr);
  USBDevice.setSerialDescriptor(serialstr);

  Serial.begin(115200);
  
  mdp.isMonome = true;
  mdp.deviceID = deviceID;
  mdp.setupAsGrid(NUM_ROWS, NUM_COLS);

  trellis.begin();

  delay(300);
  mdp.setAllLEDs(0);
  sendLeds();
  monomeRefresh = 0;
  isInited = true;
  // blink one led to show it's started up
  trellis.setPixelColor(0, 0xFFFFFF);
  trellis.show();
  delay(100);
  trellis.setPixelColor(0, 0x000000);
  trellis.show();
}

// ***************************************************************************
// **                                SEND LEDS                              **
// ***************************************************************************

void sendLeds(){
  uint8_t value, prevValue = 0;
  uint32_t hexColor;
  bool isDirty = false;
  
  for(int i=0; i< NUM_ROWS * NUM_COLS; i++){
    value = mdp.leds[i];
    prevValue = prevLedBuffer[i];
    uint8_t gvalue = gammaTable[value];
    
    if (value != prevValue) {
      //hexColor = (((R * value) >> 4) << 16) + (((G * value) >> 4) << 8) + ((B * value) >> 4); 
      hexColor =  (((gvalue*R)/256) << 16) + (((gvalue*G)/256) << 8) + (((gvalue*B)/256) << 0);
      trellis.setPixelColor(i, hexColor);

      prevLedBuffer[i] = value;
      isDirty = true;
    }
  }
  if (isDirty) {
    trellis.show();
  }

}



// ***************************************************************************
// **                                 LOOP                                  **
// ***************************************************************************

void loop() {
    trellis.tick();

    mdp.poll(); // process incoming serial from Monomes

    // refresh every 16ms or so
    if (isInited && monomeRefresh > 16) {
      keypadEvent e = trellis.read();
      uint8_t x  = e.bit.KEY % NUM_COLS;
      uint8_t y = e.bit.KEY / NUM_COLS; 

      //Serial.print((int)e.bit.KEY);
      
      if (e.bit.EVENT == KEY_JUST_PRESSED) {
        mdp.sendGridKey(x, y, 1);
        //Serial.println(" pressed");
        //trellis.setPixelColor(e.bit.KEY, 0x111111);
      }
      else if (e.bit.EVENT == KEY_JUST_RELEASED) {
        mdp.sendGridKey(x, y, 0);
        //Serial.println(" released");
        //trellis.setPixelColor(e.bit.KEY, 0x0);
      }
        sendLeds();
        monomeRefresh = 0;
    }
  
}

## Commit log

2019-12-06 getting buttons working
2019-12-14 lots of updates + case
2019-12-18 separate teensy/m0 versions
2019-12-24 fix led delay
2019-12-29 update case files
2020-01-02 add enclosure readme+pix
2020-01-02 fixes for led maps in rotation
    [MonomeSerialDevice.cpp]
2020-01-04 fix intensity on led/map
    [MonomeSerialDevice.cpp]
2020-01-09 enclosure/case updates - gamma tweaks
2020-01-19 fix led/level/col/row
2020-01-23 add new case layout
2020-02-02 Clean Up case holes/edges
2020-02-03 add 256 case
2020-02-09 fix 256 case and addresses
2020-04-09 update enclosure
2020-04-09 normalize jpg case
2020-04-09 fix image links/case
2020-07-19 fix for out of range led values
    [MonomeSerialDevice.cpp]
2020-10-26 more teensy cleanup
2020-12-02 fix setup order, speed up connection
    [neotrellis_monome_teensy.ino]
2021-01-18 updated feather M0/M4
    [neotrellis-128-12-cut.dxf]
2021-03-06 fix bad offsets for led/row led/col
    [MonomeSerialDevice.cpp]
2021-10-06 redo case files
2026-06-13 add src dir, fix usb strings, add new uf2
    [MonomeSerialDevice.cpp, debug.cpp, i2c_config.h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]
2026-08-31 update enclosure readme
